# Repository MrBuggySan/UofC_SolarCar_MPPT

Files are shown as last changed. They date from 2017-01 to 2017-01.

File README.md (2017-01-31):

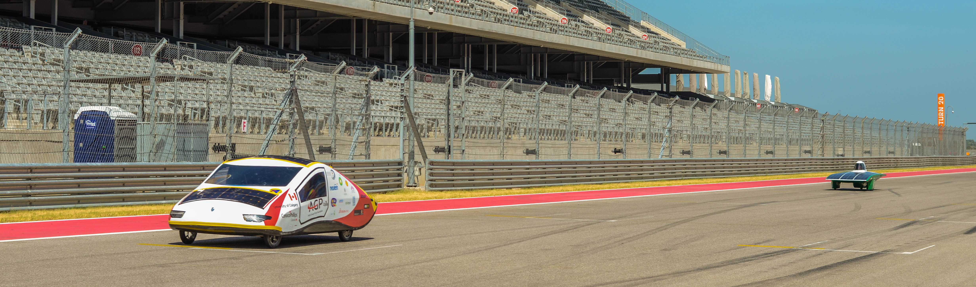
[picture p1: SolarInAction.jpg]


# [MPPT](https://en.wikipedia.org/wiki/Maximum_power_point_tracking) used by [University of Calgary Solar Car Team](http://www.calgarysolarcar.ca/) in [FSGP 2015](http://americansolarchallenge.org/)

This MPPT design is a newer version of the one used in [WSC 2013](https://www.worldsolarchallenge.org/). Off the shelf MPPTs usually cost around $1000. To save money, the team assigned me to make a custom MPPT for them. In the end the parts cost summed to $150 and it performed as expected! 

Features:
- Easy to use [LPC11C24](http://www.nxp.com/products/microcontrollers-and-processors/arm-processors/lpc-cortex-m-mcus/lpc1100-cortex-m0-plus-m0/scalable-entry-level-32-bit-microcontroller-mc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)
- A new algorithm that takes care of device inefficiencies due to clouds covering the solar cells 
- 98% maximum efficiency in static conditions 
- New testing modes (Static Voltage, Dynamic Trace, IV Trace, Open)
- 5 LEDs showing different status
- Fuses at the input and output of the device
- Working [CAN](https://en.wikipedia.org/wiki/CAN_bus) messages 

The altium files used to create the PCBs are also [here](https://github.com/MrBuggySan/UofC_SolarCar_MPPT/tree/master/Altium)

The C code is [here](https://github.com/MrBuggySan/UofC_SolarCar_MPPT/tree/master/src)

[Top view](https://github.com/MrBuggySan/UofC_SolarCar_MPPT/blob/master/TopView.jpg)

[Bottom view](https://github.com/MrBuggySan/UofC_SolarCar_MPPT/blob/master/BottomView.jpg)

[Schematics](https://github.com/MrBuggySan/UofC_SolarCar_MPPT/blob/master/MPPTSchematic.PNG)

[3D View from Altium](https://github.com/MrBuggySan/UofC_SolarCar_MPPT/blob/master/MPPTBoard.PNG)

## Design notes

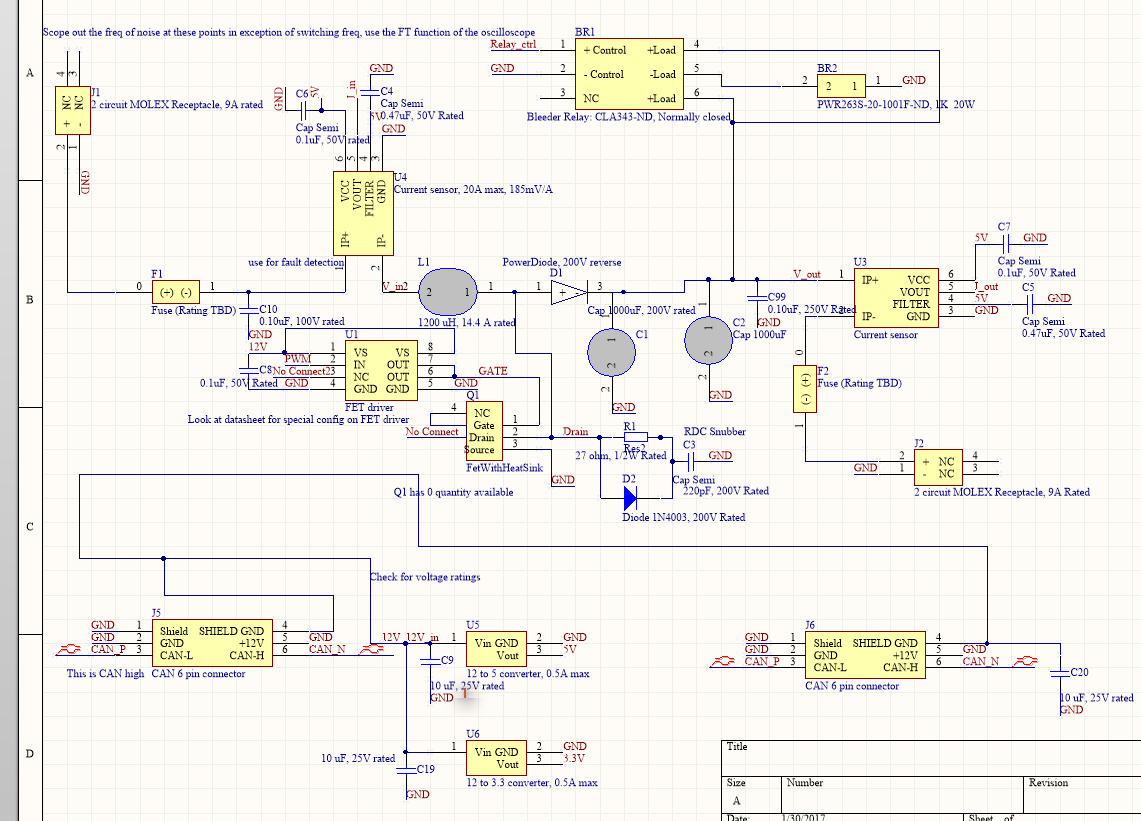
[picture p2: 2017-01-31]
MPPTSchematic.PNG

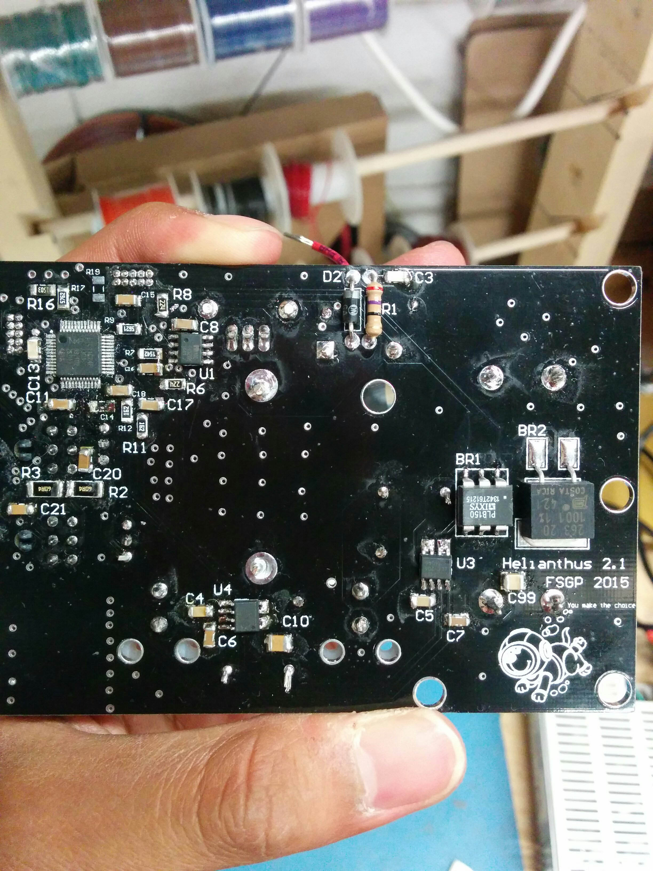
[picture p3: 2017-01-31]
BottomView.jpg

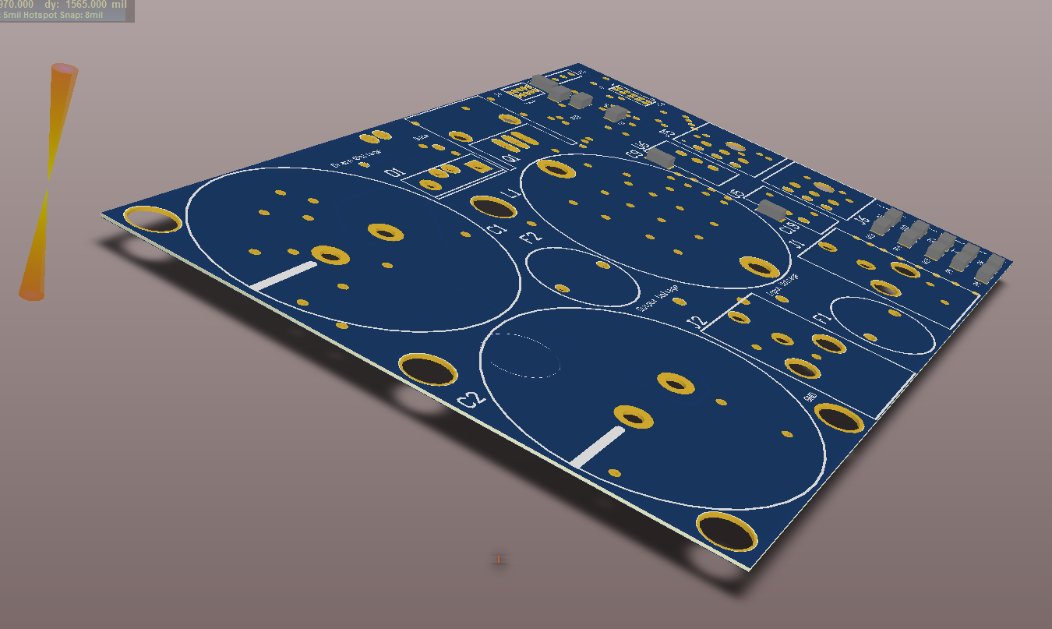
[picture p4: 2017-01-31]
MPPTBoard.PNG

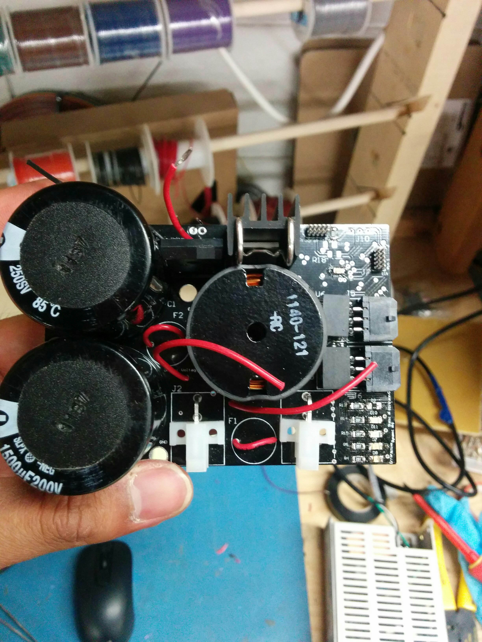
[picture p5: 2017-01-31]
TopView.jpg

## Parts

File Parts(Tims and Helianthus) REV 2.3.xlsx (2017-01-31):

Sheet: Helianthus V2
Updated as of July 22, 2015
As much as ppossible the resistors and capacitors listed are 1206 packages, so new ones should be 1206 too
HelianthusV2.1 specific |  |  |  |  |  |  |  |  |  | buy all
Part Number | Description | Quantity per MPPT | Designator | Comments | Price per item | Total Price | Amount we have | How many MPPT | Comment | don’t buy | 2015-07-11
568-6644-ND | LPC 11C24 Microcontroller | 1 | U2 |  | $6.70 | $6.70 | 0 | 0 | the one left has a damaged pin.
338-1577-ND | 1500uF Aluminum Cap | 2 | C1, C2, C100 | Output cap, will experiment which value is appopriate | $7.67 | $15.34 | 13 | 6.5 |  |  | 19
P11601-ND | 1000uF Aluminum Cap | 2 | C1, C2, C100 | Output cap, will experiment which value is appopriate |  | $0.00 | 11 | 5.5
490-8603-ND | 1.0uF Ceramic Cap | 1 |  |  |  | $0.00 |  | 0
M8377-ND | 100 uH Fixed Inductor | 1 | L1 | Big inductor, will experiment which value is appopriate | $10.48 | $10.48 |  | 0
620-1230-1-ND | Current Sensor | 2 | U3, U4 | Pretty much the same as the current sensor from Helianthus but with higher input current rating | $5.44 | $10.88 | 1 | 0.5 |  |  | 1
620-1643-1-ND | Current Sensor | 2 | U3, U4 |  |  | $0.00 | 2 | 1
399-1249-1-ND | Bypass CAP 0.1UF | 11 | C6, C7, C8, C11, C12, C13, C14, C15, C16, C17, C18 |  |  | $0.00 | 0 | 0
709-1013-1-ND | Bypass CAP 0.1 UF | 11 | C6, C7, C8, C11, C12, C13, C14, C15, C16, C17, C18 |  | $0.90 | $9.90 | 14 | 1.272727273
WM3900-ND | 2 circuit molex board side | 2 | J1, J2 |  | $1.04 | $2.08 | 13 | 6.5 |  |  | 10
WM3700-ND | 2 circuit molex wire side | 2 |  |  |  | $0.00 |  | 0 | I don't see anymore of this in the shop
WM1815-ND | CAN 6 pin connector | 2 | J5,J6 |  | $2.34 | $4.68 |  | 0
945-1037-ND | 12-5V converter | 1 | U5 |  | $9.33 | $9.33 | 4 | 4 |  |  | 9
587-1353-1-ND | Bypass CAP 10 uF | 3 | C9, C19, C20 |  | $0.29 | $0.87 | 4 | 1.333333333 |  |  | 20
RHM60.4BFCT-ND | CAN resistors | 2 | R2, R3 | RHM30BGCT-ND - incorrect part #, this is 30 ohms | $0.60 | $1.20 | 19 | 9.5 |  |  | 25
945-1035-ND | 12-3.3V converter | 1 | U6 |  | $9.33 | $9.33 | 8 | 8 |  |  | 9
1N5226BFSCT-ND | Diode Zener 3.3V | 4 | D3, D4, D5, D6 |  |  | $0.00 |  | 0
399-1268-1-ND | Bypass CAP 0.1 UF | 1 | C10 |  | $0.49 | $0.49 | 7 | 7
490-3541-1-ND | Bypass CAP 0.1 UF | 1 | C99 |  | $0.56 | $0.56 | 7 | 7
RMCF1206JT220KCT-ND | 220K resistor | 2 | R6, R8 |  | $0.15 | $0.30 |  | 0
P15.4KFCT-ND | 15.4K resistor | 1 | R7 |  | $0.15 | $0.15 | 45 | 45
P5.11KFTR-ND | 5.11K resistor | 1 | R9 |  |  | $0.00 | 250 | 250
P5.62KFCT-ND | 5.62k resistor | 1 | R9 |  | $0.15 | $0.15 | 44 | 44
P12KECT-ND | 12K resistor | 1 | R10 |  | $0.15 | $0.15 | 48 | 48 |  |  | 50
609-3712-ND | 10 pin SWD header | 2 | J4, J7 |  | $0.88 | $1.76 | 9 | 4.5 |  |  | 14
P1.6KECT-ND | 1.6K resistor | 2 | R11, R12 |  | $0.15 | $0.30 | 43 | 21.5
399-9300-1-ND | 1nF Capacitor | 1 | C21 |  | $0.40 | $0.40 | 7 | 7 |  |  | 10
160-1189-1-ND | Yellow LED | 1 | D9 |  | $0.49 | $0.49 | 8 | 8 |  |  | 10
160-1643-1-ND | Blue LED | 1 | D10 |  | $0.69 | $0.69 | 18 | 18 |  |  | 4
160-1403-1-ND | Orange LED | 1 | D11 |  | $0.51 | $0.51 | 7 | 7 |  |  | 11
RHM150KCJCT-ND | 150K resistors | 1 | R16 |  | $0.15 | $0.15 | 89 | 89
P57.6KFCT-ND | 57.6K resistor | 1 | R17 |  | $0.15 | $0.15 | a lot | #VALUE!
255-2154-5-ND | Bleeder Relay | 1 | BR1 |  |  | $0.00 |  | 0
CLA343-ND | Bleeder Relay | 1 | BR1 |  | $6.91 | $6.91 |  | 0 |  |  | 4
PWR263S-20-1001F-ND | 1K Bleeder resistor | 1 | BR2 |  | $5.07 | $5.07 |  | 0
696-1350-ND | 500 ohm Bleeder | 1 | BR2 |  |  | $0.00 |  | 0
507-1638-ND | 8 A Fuse | 2 |  |  | $0.40 | $0.80 |  | 0 |  |  | 23
486-1730-ND | Fuseholder | 2 | F1, F2 |  | $6.04 | $12.08 |  | 0 |  |  | 23
486-1734-ND | Fuse Cap | 2 | F1, F2 |  | $3.83 | $7.66 |  | 0
P10KECT-ND | 10K programming resistors | 3 | R18, R19, R20, R21, R22 |  | $0.15 | $0.45 | 14 | 4.666666667
http://www.nve.com/webstore/catalog/product_info.php?cPath=27_28&products_id=544 | 12V in current sensor | 1 | U7 |  | $5.25 | $5.25 |  | 0
Helianthus
Part Number | Description | Quantity per MPPT | Designator | Comments | Price | Toal Price | Amount we have | How many MPPTS
WA-T220-101E-ND | Heatsink | 1 | Q1 |  | $2.86 | $2.86 | 10 | 10 |  |  | 5
IPP110N20N3 G-ND | Power FET | 1 | Q1 |  | $9.10 | $9.10 |  | 0
576-1210-1-ND | FET Driver | 1 | U1 |  | $2.75 | $2.75 | 5 | 5 |  |  | 4
565-3692-ND | 1200uF Aluminum Cap | 3 | C1, C2, C100 | P13801-ND obsolete |  | $0.00 |  | 0
M8378-ND | 120 uH Fixed Inductor | 1 | L1 | Big inductor, will experiment which value is appopriate |  | $0.00 | 10 | 10 |  |  | 14
APT60S20BG-ND | Power Diode | 1 | D1 | I'm not sure what improvement will be done for this part, may have to look in to diode reverse current | $7.71 | $7.71 | 5 | 5 |  |  | 10
281-1120-ND | 6 pin connector Board side | 1 |  | Too expensive |  | $0.00 |  | 0
281-1057-ND | 6 pin connector wire side | 1 |  | Too expensive |  | $0.00 |  | 0
277-1468-ND | Main Connector (board) | 1 |  | Too expensive |  | $0.00 |  | 0
277-1870-ND | Main Connector (wire) | 1 |  | Too expensive |  | $0.00 |  | 0
160-1404-1-ND | Green LED | 1 | D7 | This is a new Green LED | $0.53 | $0.53 | 17 | 17 |  |  | 11
160-1187-1-ND | Red LED | 1 | D8 |  | $0.49 | $0.49 | 4 | 4 |  |  | 13
478-1432-1-ND | 220pF Snubber Cap | 1 | C3 |  | $0.45 | $0.45 | 4 | 4
1N4003GOS-ND | Snubber Diode | 1 | D2 |  | $0.26 | $0.26 | 3 | 3
CF12JT27R0CT_ND | 27 Ohm Snub Res | 1 | R1 |  | $0.15 | $0.15 | a lot | #VALUE!
311-1436-1-ND | 0.47uF 50V CAP | 2 | C4, C5 |  | $0.30 | $0.60 | 19 | 9.5 |  |  | 25
P1.0KECT-ND | 1k Res for LEDs | 5 | R4, R5, R13, R14, R15 |  | $0.15 | $0.75 | a lot | #VALUE!
MT7318-ND | 6A AC/DC Sensor Current Hall | 2 |  |  | $21.03 | $42.06 |  | 0 |  |  | 18
 |  |  |  |  | Total | $192.97
Random

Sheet: Helianthus
Helianthus MPPT BOM (Apr 16 2013)
Part Number | Description | Quantity | Unit Price | Extended Price | Association | Designator | Description/ Comments/ Problems | Amount we have | Amount we need to order for this many MPPTs: | 10
M8378-ND | 120uH Inductor | 1 | $14.70 | $14.70 | MPPT | L2 |  | 11 | 0
APT60S20BG-ND | Power Diode | 1 | $6.05 | $6.05 | MPPT | D3 |  | 11 | 0
WA-T220-101E-ND | Heatsink | 1 | $1.81 | $1.81 | MPPT | Q1 | Tim's | 12 | 0
IPP110N20N3 G-ND | Power FET | 1 | $8.58 | $8.58 | MPPT | Q1 | Tim's | 12 | 0
MCP3204T-CI/SLCT-ND | 12 Bit A-D | 1 | $4.00 | $4.00 | MPPT | U5 |  | 5 | 5
MCP2515-I/SO-ND | CAN Controller | 1 | $2.11 | $2.11 | MPPT | U6 |  | 15 | 0
MCP2551-I/SN-ND | CAN Transceiver | 1 | $1.19 | $1.19 | MPPT | U7 |  | 15 | 0
620-1230-1-ND | Current Sensor Hall | 1 | $4.14 | $4.14 | MPPT | U8 |  | 3 | 7
576-1210-1-ND | FET Driver | 1 | $3.02 | $3.02 | MPPT | U2 |  | 22 | 0
LM4040BIM3-5.0+TCT-ND | 5V REF | 1 | $1.24 | $1.24 | MPPT | U4 |  | 6 | 4
428-1598-ND | Micro-controller | 1 | $6.44 | $6.44 | MPPT | U3 |  | 9 | 1
277-1468-ND | Main Connector (board) | 1 | $5.78 | $5.78 | MPPT | J2 |  | 10 | 0
277-1870-ND | Main Connector (wire) | 1 | $6.84 | $6.84 | MPPT | J2 | Not on the PCB | 10 | 0
S1111E-36-ND | Right Angle Pins | 1 | $2.67 | $2.67 | MPPT | J4 |  | 9999 | 0
281-1120-ND | 6 Pin Connector (Board) | 1 | $2.30 | $2.30 | MPPT | J1 |  | 12 | 0
281-1057-ND | 6 Pin Connector (wire) | 1 | $7.36 | $7.36 | MPPT | J1 |  | 13 | 0
A19481-ND | Prog Pins | 1 | $0.43 | $0.43 | MPPT | J3 |  | 42 | 0
P13520-ND | 150uF Aluminum Cap 200V | 1 | $1.72 | $1.72 | MPPT | J3 | Replaced the 50V cap with this 200V | 10 | 0
P13801-ND | 1200uF Aluminum Cap | 2 | $4.67 | $9.34 | MPPT | C4, C5 | May not need to be as big according to Dan Young | 24 | 0
478-1432-1-ND | 220pF Cap | 1 | $0.35 | $0.35 | MPPT | C15 |  | 4 | 6
399-5714-1-ND | 0.1uF 25 V cap | 3 | $0.37 | $1.11 | MPPT | C6, C7, C8 |  | 7 | 23
490-1809-1-ND | 4.7uF 25V Cap | 1 | $0.36 | $0.36 | MPPT | C13 | For decoupling the 12V line, other decoup caps only rated to 6.3V | 4 | 6
311-1436-1-ND | 0.47uF 50V CAP | 1 | $0.22 | $0.22 | MPPT | C12 | Replace cap that went obsolete (445-4020-1-ND) | 1 | 9
 |  | 1 | $0.11 | $0.11 | MPPT | R10 |  | 11 | 0
P1.0KECT-ND | 1k Res for LEDs | 2 | $0.11 | $0.22 | MPPT | R2, R3 |  | 61 | 0
P470ECT-ND | 470 ohm resistor | 1 | $0.11 | $0.11 | MPPT | R7 |  | 22 | 0
P196KFCT-ND | 196k res | 1 | $0.11 | $0.11 | MPPT | R9 |  | 29 | 0
P5.6KECT-ND | 5.6K res | 1 | $0.11 | $0.11 | MPPT | R4 |  | 29 | 0
P3.9KECT-ND | 3.9k res | 1 | $0.11 | $0.11 | MPPT | R5 |  | 68 | 0
P39KECT-ND | 39k res | 1 | $0.11 | $0.11 | MPPT | R6 |  | 45 | 0
P20KECT-ND | 20k res | 1 | $0.12 | $0.12 | MPPT | R8 |  | 30 | 0
XC1109CT-ND | Resonator | 1 | $0.76 | $0.76 | MPPT | X1 |  | 1 | 9
1N4003GOS-ND | Snubber Diode | 1 | $0.20 | $0.20 | MPPT | D4 |  | 16 | 0
Helianthus unique:
LM2674M-5.0/NOPB-ND | 12-5V Converter | 1 | $3.28 | $3.28 | MPPT | U1 | New 12-5 to replace the original replacement | 0 | 10
445-1606-1-ND | 4.7 uF cap | 1 | $0.35 | $0.35 | MPPT | C1 | Goes with new 12-5 | 15 | 0
478-7021-1-ND | 100 nF Cap | 1 | $0.13 | $0.13 | MPPT | C2 | Goes with new 12-5 | 11 | 0
445-7688-1-ND | 10 nF cap | 1 | $0.37 | $0.37 | MPPT | C21 | Goes with new 12-5 | 12 | 0
565-3127-1-ND | 27 uF Cap | 1 | $2.01 | $2.01 | MPPT | C22 | Goes with new 12-5 | 14 | 0
MBR0520LT1GOSCT-ND | Schottky Diode | 1 | $0.38 | $0.38 | MPPT | D5 | Goes with new 12-5 | 28 | 0
445-6571-1-ND | 100 uH Inductor | 1 | $0.68 | $0.68 | MPPT | L1 | Goes with new 12-5 | 12 | 0
P11515CT-ND | Green LED | 1 | $0.52 | $0.52 | MPPT | D1 | New LED to replace the one that went Obsolete, again | 16 | 0
160-1187-1-ND | Red LED | 1 | $0.38 | $0.38 | MPPT | D2 | New LED to replace the one that went Obsolete | 16 | 0
445-4113-1-ND | 10 uF 0805 cap | 6 | $0.24 | $1.44 | MPPT | C14, C16, C17, C18, C19, C20 | Decoupling cap across every IC's VCC that george wanted | 50 | 10
817-FTR-J2AK012W | Dual STSP Relay | 1 | $17.95 | $17.95 | MPPT | J5 | Relay as required by WSC regulations | 10 | 0
F3068-ND | Varistor for relay | 1 | $0.69 | $0.69 | MPPT | V1 | Varistor to prevent kickback when relay opens | 15 | 0
473-1121-ND | Thermal Paste | 0 | $15.88 | $0.00 | MPPT |  | For heatsink - only need to buy one tube | 1
P4675-ND | 1uF Film Cap | 1 | $0.75 | $0.75 | MPPT | C23 | Bypass cap for the FET Driver - SHARE HOLE WITH C22!! | 15 | 0
445-5258-ND | 0.1uF Ceramic Cap | 2 | $0.32 | $0.64 | MPPT | C24, C25 | Bypass cap for the FET Driver | 20 | 0
IXFK320N17T2-ND | GigaMOS TrenchT2 | 0 | $23.02 | $0.00 | MPPT-testing |  | Possibly a better Mosfet. Rds=5.2mOhm instead of 11mOhm | 0
FGA180N33ATDTU-ND | IGBT | 0 | $4.57 | $0.00 | MPPT-testing |  | 330V IGBT with a 1.4V drop when on. Best I could find at 330V, beat the best I could find at lower voltages that were in stock | 1
Total Part Cost (USD) |  |  |  | $123.29
Testpoint: | Description
TP0 | 12V line
TP1 | 5V line
TP3 | CH0 of ADC
TP4 | CH1 of ADC
TP5 | CH2 of ADC
TP6 | Vref

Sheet: Tim's
Power Components | Description | Quantity
M8379-ND | Inductor | 1
APT60S20BG-ND | Diode | 1
WA-T247-101E-ND | FET Heatsink | 1
IRFP4668PBF-ND | Mosfet | 1
IC’s
MCP3208-BI/P-ND | 12 bit A-D Converter | 1
MCP2515-I/P-ND | CAN Controller | 1
MCP2551-I/P-ND | CAN Transceiver | 1
620-1230-1-ND | Current Sensor | 1
945-1037-ND | 12V-5V | 1
576-1211-ND | FET Driver | 1
LT1019CN8-5#PBF-ND | Voltage Reference 5V | 1
428-1596-ND | Cypress Chip | 1
Connectors
277-1468-ND | Main Connector (Board) | 1
277-1870-ND | Main Connector (Wire) | 1
S1111E-36-ND | Right Angle Pins | 1
281-1120-ND | 6 pin connector | 1
Capacitors
P13459-ND | 100uF input cap | 1
P6826-ND | 680uF output Cap | 2
399-4184-ND | 0.47nF snubber 200V Cap | 1
445-5348-ND | 1.5uF cap 50V | 5
445-5352-ND | 6.8uF cap 25V | 10
445-5313-ND | 0.47uF | 1
Resistors
RC12JB27R0-ND | Snubber Resistor 27 ohm | 1
LED’s
P607-ND | Green LED 3mm | 1
P606-ND | Red LED 3mm | 1
Other
X909-ND | Oscillator 20Mhz | 1
240-2448-2-ND | CAN Inductor | 1
1N4003GOS-ND | Snubber Diode 200V | 1
A19481-ND | programming pins | 1

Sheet: combined data
Component | Helianthus |  | Tim's
 | Part Number | Description | Part Number | Description
Inductor | M8378-ND | 120uH Inductor | M8379-ND | Inductor (Power Components)
 | 445-6571-1-ND | 100 uH Inductor | 240-2448-2-ND | CAN Inductor
Capacitor | P13520-ND | 150uF Aluminum Cap 200V | P13459-ND | 100uF input cap
 | P13801-ND | 1200uF Aluminum Cap | P6826-ND | 680uF output Cap
C15 | 478-1432-1-ND | 220pF Cap | 399-4184-ND | 0.47nF snubber 200V Cap
C6, C7, C8 | 399-5714-1-ND | 0.1uF 25 V cap | 445-5348-ND | 1.5uF cap 50V (5 of these)
C13 | 490-1809-1-ND | 4.7uF 25V Cap | 445-5352-ND | 6.8uF cap 25V (10 of these)
C12 | 311-1436-1-ND | 0.47uF 50V CAP | 445-5313-ND | 0.47uF
capacitors for 12-5 | 445-1606-1-ND | 4.7 uF cap
 | 478-7021-1-ND | 100 nF Cap
 | 445-7688-1-ND | 10 nF cap
 | 565-3127-1-ND | 27 uF Cap
for FET Driver | P4675-ND | 1uF Film Cap
 | 445-5258-ND | 0.1uF Ceramic Cap
IC's and associates | MCP2515-I/SO-ND | CAN Controller | MCP2515-I/P-ND | CAN Controller
 | MCP2551-I/SN-ND | CAN Transceiver | MCP2551-I/P-ND | CAN Transceiver
 | 576-1210-1-ND | FET Driver | 576-1211-ND | FET Driver
 | 428-1598-ND | Micro-controller | 428-1596-ND | micro-controller
 | LM4040BIM3-5.0+TCT-ND | 5V REF | LT1019CN8-5#PBF-ND | Voltage Reference 5V
 | MCP3204T-CI/SLCT-ND | 12 Bit A-D | MCP3208-BI/P-ND | 12 bit A-D Converter
 | 620-1230-1-ND | Current Sensor Hall | 620-1230-1-ND | Current Sensor
FET | IPP110N20N3 G-ND | Power FET | IRFP4668PBF-ND | Mosfet
 | WA-T220-101E-ND | Heatsink | WA-T247-101E-ND | FET Heatsink
Connectors | 277-1468-ND | Main Connector (board) | 277-1468-ND | Main Connector (Board)
 | 277-1870-ND | Main Connector (wire) | 277-1870-ND | Main Connector (Wire)
 | 281-1120-ND | 6 Pin Connector (Board) | S1111E-36-ND | Right Angle Pins
 | 281-1057-ND | 6 Pin Connector (wire) | 281-1120-ND | 6 pin connector

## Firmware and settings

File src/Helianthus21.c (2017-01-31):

/*
===============================================================================
 Name        : AB_Test.c
 Author      : $(author)
 Version     :
 Copyright   : $(copyright)
 Description : main definition
===============================================================================
*/


#include "chip.h"

// TODO: insert other include files here
#include <cr_section_macros.h>
#include "Helianthus21_utils.h"
#include "Helianthus21_modes.h"


// TODO: insert other definitions and declarations here
#define TICKRATE_HZ1 (3) /* 10 ticks per second */
#define TICKRATE_HZ2 (4) /* 11 ticks per second */
//#define TEST_CCAN_BAUD_RATE 500000
#define TEST_CCAN_BAUD_RATE 125000
//user must define unique MPPT_ID for each MPPT
//#define MPPT_TRACK_TRANSMIT_ID 0x410 //MPPT#1
//#define MPPT_RECEIVE 0x300
#define CAN_SEND_WAIT 5


const uint16_t coutVoltage_limit=135;// 135V max output voltage
const uint16_t cinVoltage_limit=50;// 50V max input voltage -AB 6/17/2015
const uint16_t Current_limit=6 ;//Protect the 8A fuse



uint8_t CAN_send_count=0;
uint8_t Dynamic_count=0;

uint16_t max_duty_cycle=400;
uint8_t min_duty_cycle=0;
uint16_t delta_voltage= 3;//50 corresponds to 2.465V at the input
uint8_t go_towards_higher_current=1;
uint8_t fail_count=0;
uint8_t tracking_speed=0;


uint8_t Track=1;
uint8_t data[8];
uint8_t receive_data[8];
uint8_t wait_for_tx_finished=0;


//CCAN_MSG_OBJ_T receive_obj;
CCAN_MSG_OBJ_T transmit_obj;
uint16_t duty_cycle=600;// Think of a good guess here -AB 1/8/2015

uint16_t int_input_voltage=0;
float f_input_voltage=0;
uint16_t int_input_current=0;
float f_input_current=0;

uint16_t int_output_voltage=0;
float f_output_voltage=0;
uint16_t int_output_current=0;
float f_output_current=0;

uint16_t int_12V_voltage=0;
float f_12V_voltage=0;
uint16_t int_12V_current=0;
float f_12V_current=0;

uint8_t Arrayside_over=0;
uint8_t Batteryside_over=0;

uint8_t MPPT_mode=0;
uint8_t message_num=0;
uint8_t dlc=8;

uint16_t Dynamic_iteration=0;
uint16_t dynamic_max_duty_power=0;
unsigned long dynamic_max_previous_power=0;
#define DYNAMIC_PERIODIC_DELAY 24
//uint8_t dynamic_periodic_delay=12;



int main(void)
{

//	receive_obj.mode_id=CAN_MSGOBJ_STD|MPPT_RECEIVE;
//	receive_obj.mask=0x4;
//	receive_obj.msgobj=1;

//	transmit_obj.mode_id=CAN_MSGOBJ_STD|MPPT_TRACK_TRANSMIT_ID;
//	transmit_obj.mask=0x0;
//	transmit_obj.msgobj=2;

    SystemCoreClockUpdate(); //System clock at 48 MHz -AB 1/7/2015

    duty_cycle=max_duty_cycle*0.25;
    Configure_MPPT(duty_cycle);

    //float test_message=65.65;

    wait_for_tx_finished=0;

    //Relay_OPEN();

    receive_data[0]=0x0;//This is the default value so we can have static alg as default -AB 6/17/2015

    //TODO: compare the difference between this code and ccan_romc code

    Check_Voltage_Current_at_Input_Output();
   	while(1)
   	{

   		Check_Voltage_Current_at_Input_Output();

    	if(Track==1)
    	{

    		//Send_Status_to_CCS(receive_data[0]);
    		//Send_Status_to_CCS();
    		switch(receive_data[0])
    		{
    			case 0:
    				MPPT_mode=0;

    				track_MPP_static();
    				//Send_Data_to_CCS(STATIC_);

      				break;
    			case 1:
    				MPPT_mode=1;
    				if (Dynamic_count>DYNAMIC_PERIODIC_DELAY)
    				{
						Dynamic_iteration=1;
    				}
    				track_MPP_dynamic();
    				//Send_Data_to_CCS(DYNAMIC_);
    				break;
    			case 2:
    				MPPT_mode=2;
    				//Disable the CAN sending interrupt
    				//NVIC_DisableIRQ(TIMER_16_1_IRQn);
    				IV_trace();
    				//Enable the CAN sending interrupt
    				//NVIC_EnableIRQ(TIMER_16_1_IRQn);
    				receive_data[0]=0;
    				duty_cycle=0.75*max_duty_cycle;
    				Set_PWM_Duty_Cycle(duty_cycle);
    				break;
    			case 3:
    				//OPEN mode
    				MPPT_mode=3;
    				duty_cycle=0;
					Set_PWM_Duty_Cycle(duty_cycle);
					break;
    			case 7:
    				//Boost efficiency test mode
    				MPPT_mode=7;
    				NVIC_DisableIRQ(TIMER_16_1_IRQn);
    				Boost_Efficiency();
    				NVIC_EnableIRQ(TIMER_16_1_IRQn);
    				break;
    			case 9:
    				//Static voltage mode
    				MPPT_mode=9;
    				//duty_cycle=0.25*max_duty_cycle;

    				duty_cycle=0;
    				Set_PWM_Duty_Cycle(duty_cycle);
    				break;
    			case 10:
    				//Static voltage mode
    				MPPT_mode=10;
    				duty_cycle=0.25*max_duty_cycle;
    				Set_PWM_Duty_Cycle(duty_cycle);
    				break;

    		}


    	}
    	else
    	{
    		MPPT_mode=3;
    		Check_Voltage_Current_at_Input_Output();
    		duty_cycle=0;
    		Set_PWM_Duty_Cycle(duty_cycle);
//    		Send_Status_to_CCS(receive_data[0]);
//    		Send_Data_to_CCS(OPEN);
    	}

    	//TODO: how long is the appropriate delay?
    	uint8_t i=0;
    	for(i=0; i<25 ; i++)
    	{
    		//Delay();
    		Check_Voltage_Current_at_Input_Output();
    	}

    	Delay();


    	send_fucking_CAN();
    	CAN_send_count++;

    	//LED_TEST();

    }


    return 0;
}

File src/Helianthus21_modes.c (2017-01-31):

/*
 * Helianthus21_modes.c
 *
 *  Created on: May 2, 2015
 *      Author: Andrei
 */
#include "chip.h"
#include <cr_section_macros.h>
#include "Helianthus21_utils.h"

extern uint16_t max_duty_cycle;
extern uint8_t min_duty_cycle;
extern uint16_t delta_voltage;
extern uint8_t Track;
extern uint8_t go_towards_higher_current;
extern uint8_t Track;
extern uint8_t fail_count;
extern uint16_t duty_cycle;
extern uint8_t data[8];
extern uint8_t Dynamic_count;
extern uint16_t Dynamic_iteration;
extern unsigned long dynamic_max_previous_power;
extern uint16_t dynamic_max_duty_power;
extern uint8_t receive_data[8];
extern uint8_t wait_for_tx_finished;


#define BOOST_REQ_CURRENT_1A 230 //This is 1A
//#define BOOST_REQ_CURRENT_1A 900 //This is 1A

#define BOOST_REQ_CURRENT_2A 323 //This is 2A
#define BOOST_REQ_CURRENT_3A 410 //This is 3A
#define BOOST_REQ_CURRENT_4A 500 //This is 4A
#define BOOST_REQ_CURRENT_5A 1004 //This is 5A

#define ALG_AVG 40


#define DYNAMIC_PERIOD 10
//static ADC_CLOCK_SETUP_T ADCSetup;


//TODO: This function is low priority
void Boost_Efficiency(void)
{
	uint16_t Req_input_current=BOOST_REQ_CURRENT_4A; //holder for the CAN message input requirement -AB 4/18/2015
	uint16_t voltage, current;
	//get the required input current here -AB 4/18/2015
	uint8_t message_num=0;

	while(1)
	{
		Read_ADC_Channel(ADC_CH6,&current);
		//within +/-5% value of the required current?
		if(current<Req_input_current)
		{
			duty_cycle+=1;
			Set_PWM_Duty_Cycle(duty_cycle);
		}

		if(current>Req_input_current)
		{
			duty_cycle-=1;
			Set_PWM_Duty_Cycle(duty_cycle);
		}


		uint8_t i=0;
		for(i=0; i<5 ; i++)
		{
			Delay();
			Check_Voltage_Current_at_Input_Output();
		 }
		if(receive_data[0] !=7)
			return;
		Read_ADC_Channel(ADC_CH1,&voltage);//Input Voltage
		Read_ADC_Channel(ADC_CH6, &current);//Input Current
		data[0]=voltage;
		data[2]=current;
		Read_ADC_Channel(ADC_CH3,&voltage);//Output Voltage
		Read_ADC_Channel(ADC_CH0, &current);//Output Current
		data[4]=voltage;
		data[6]=current;
		uint8_t dlc=8;
		message_num++;
		CANsend(data, &dlc, &message_num);

//		while (wait_for_tx_finished)
//			{
//
//			}

	};


}


void IV_trace(void)
{
	uint16_t current=0;
	uint16_t voltage=0;
	uint8_t dlc=8;
	uint8_t message_num=0;
	for(duty_cycle=min_duty_cycle; duty_cycle<=max_duty_cycle;	duty_cycle++)
	{

		Set_PWM_Duty_Cycle(duty_cycle);
		Delay();
		Delay();
		Delay();
		Delay();
		Check_Voltage_Current_at_Input_Output();
		if(Track == 0)
			return;

		Read_ADC_Channel(ADC_CH1,&voltage);//Input Voltage
		Read_ADC_Channel(ADC_CH6, &current);//Input Current
		data[0]=voltage;
		data[1]=voltage>>8;
		data[2]=current;
		data[3]=current>>8;
		Read_ADC_Channel(ADC_CH3,&voltage);//Output Voltage
		Read_ADC_Channel(ADC_CH0, &current);//Output Current
		data[4]=voltage;
		data[5]=voltage>>8;
		data[6]=current;
		data[7]=current>>8;
		uint8_t AB_probe3=data[4];
		uint8_t AB_probe4=data[5];
		CANsend(data, &dlc, &message_num);
		Delay();
		Delay();
		Delay();
		Delay();
		message_num++;

	}

}



//TODO: look over this function
// Track the MPP
void track_MPP_static(void)
{
	/* Pseudo-code:
	 * -save initial duty cycle before any changes to duty cycle is done
	 * -take readings of input voltage and current then average
	 * -calculate the initial power
	 * -while the absolute delta voltage (abs difference between init V and V after the change of duty cycle)
	 *                                       resulting from duty cycle change has not been reached
	 * 		-if go towards higher current =1 then increase duty cycle
	 * 		-if go towards higher current =0 then decrease duty cycle
	 * 		-re-read the input voltage to be used for abs difference calculation
	 * -delay to let the power change to take effect
	 * -take readings of input voltage and current then average
	 * -calculate the final power
	 * -compare the initial and final power
	 * 		-if final power is lesser than initial power then set go towards higher current to opposite of what it was
	 * 		-else set go towards higher current as it was
	 *
	 *
	 */

	uint8_t tracking_speed;
	// Variables needed to for this function to work
	unsigned char i = 0;
	uint16_t temp_current=0; // Used to store the current
	uint16_t current=0;
	uint16_t temp_voltage=0; // Store the value of voltage
	uint16_t voltage=0;
	uint16_t initial_duty_cycle = duty_cycle;

	unsigned long beginning_power;
	uint16_t beginning_current;
	uint16_t beginning_voltage;
	unsigned long end_power;
	uint16_t end_current;
	uint16_t end_voltage;

	// Increment the PWM
	// Also reduce the rate of oscillation when near the MPP
	if (fail_count == 0)
		tracking_speed = 4;
	else if (fail_count == 1)
		tracking_speed = 2;
	else
		tracking_speed = 1;

	// Measure the input current and voltage


	// Get four sets of current and voltage values, then calculate the average.
	for (i=0; i<ALG_AVG;i++)
	{
		// Get current data. This function needs to be written.
		//get_current_temp();

		Read_ADC_Channel(ADC_CH1, &voltage);
		Read_ADC_Channel(ADC_CH6, &current);
		Check_Voltage_Current_at_Input_Output();
		if (Track == 0)
		{
			return;
		}
		// Store input and current voltages. Still have to define data_array
		temp_current = temp_current + current;
		temp_voltage = temp_voltage + voltage;

	}

	// Calculate the initial power
 	beginning_current = temp_current/ALG_AVG;
	beginning_voltage = temp_voltage/ALG_AVG;

	beginning_power = beginning_voltage * beginning_current;

	//test duty cycle
	uint16_t duty_cycle__=duty_cycle;

	Check_Voltage_Current_at_Input_Output();
	if (Track == 0)
	{
		return;
	}

	//TODO: we may have to change delta voltage as we arrive the MPP
	while ( absdifference(voltage,beginning_voltage) < delta_voltage )
	{

		if (go_towards_higher_current ==1) // Increase duty cycle
			//duty_cycle = duty_cycle + tracking_speed; // Adjust tracking speed.
			duty_cycle = duty_cycle + 1;
		else if (go_towards_higher_current == 0) // Decrease duty cycle in this scenario
			//duty_cycle = duty_cycle - tracking_speed; // Adjust tracking speed.
			duty_cycle = duty_cycle - 1;
		duty_cycle__=duty_cycle;

		if (duty_cycle >= min_duty_cycle && duty_cycle <= max_duty_cycle)
			// Must be in this range for the following to take effect
			Set_PWM_Duty_Cycle(duty_cycle);
		// Check if updated duty cycle is out of range and undo change if necessary
		else
		{
			go_towards_higher_current = !go_towards_higher_current;
			duty_cycle = initial_duty_cycle;
			return;
		}

		// Re measure current
		Read_ADC_Channel(ADC_CH1, &voltage);
		//Read_ADC_Channel(ADC_CH6, &current);
//		Check_Voltage_Current_at_Input_Output();
//		if(Track == 0)
//			return;
//		Check_Voltage_Current_at_Input_Output();
//		if (Track == 0)
//		{
//			return;
//		}

	}

	for (i=0; i<10; i++)
	{
		Delay();
		Check_Voltage_Current_at_Input_Output();
				if (Track == 0)
				{
					return;
				}
	}

	// Re measure input current and voltage
	temp_current = 0;
	temp_voltage = 0;
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
